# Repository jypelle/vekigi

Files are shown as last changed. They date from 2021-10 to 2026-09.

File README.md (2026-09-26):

# Vekigi

A 3D printable internet radio based on Golang and a Raspberry Pi Zero WH.

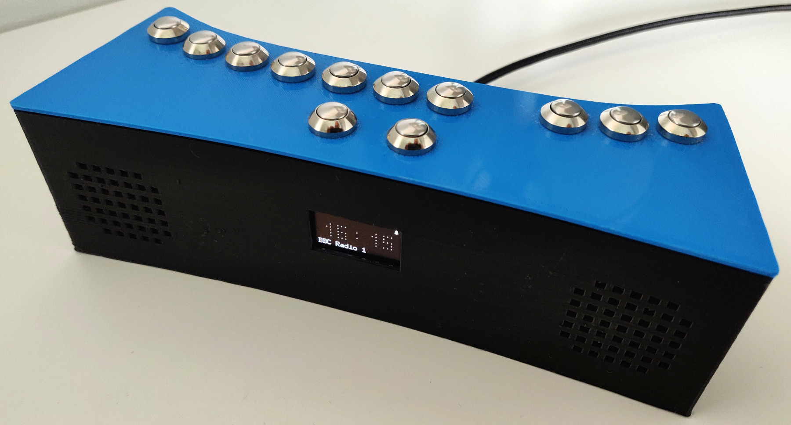
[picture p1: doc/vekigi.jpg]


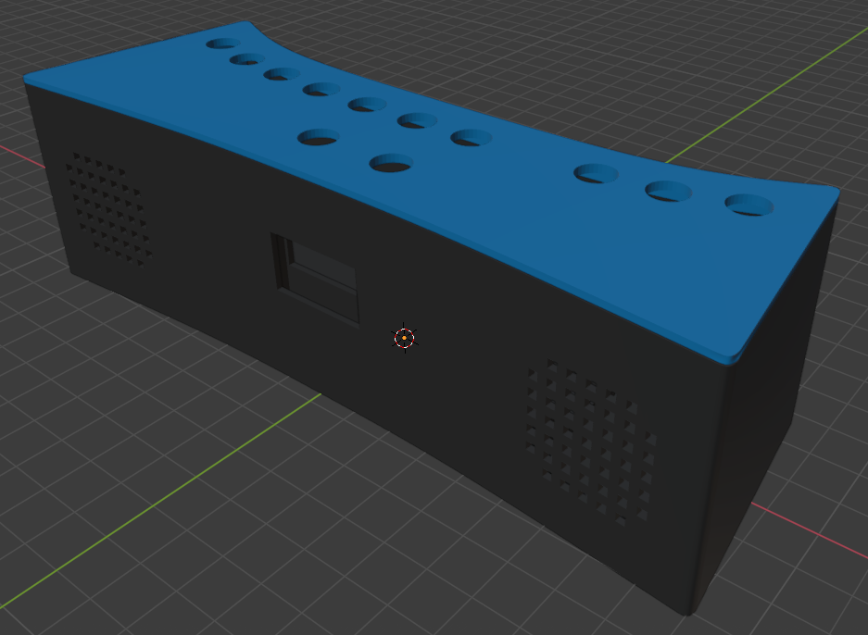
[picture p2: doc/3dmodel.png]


*NB: Vekiĝi means "to wake up" in esperanto.*

## Key features

- Alarm clock with adjustable snooze time (that's a killer feature 😜)
- REST API to easily interface with home automation
- Play
  - webradios (any audio stream playable by [VLC](https://www.videolan.org))
  - local playlists (folders with music files)
  - or remote playlists (through [Mifasol music server](https://github.com/jypelle/mifasol))

Read [the building instructions](doc/building.md) to build your own Vekigi and tune it with [the manual](doc/manual.md).

See [the changelog](CHANGELOG.md) for the release notes.

## Development

Requirements: [Go 1.27+](https://go.dev/dl/) and [Task](https://taskfile.dev).

| Command | Description |
|---|---|
| `task build` | Build the Raspberry Pi Zero binary (ARMv6) into `release/linux-arm/vekigisrv` |
| `task deploy` | Build, then deploy and restart the `vekigisrv` service on `pi@vekigi` through SSH |
| `task simulator` | Run Vekigi on your computer, the OLED display being simulated in a window (debug mode) |

### Simulator

The simulator is only included in binaries built with `-tags simulator`: it displays the OLED screen in a window and simulates the buttons with the keyboard.

| Key | Button |
|---|---|
| `1`-`6` (top row or numpad) | Digits |
| `P` | Playlist |
| `Enter` | Alarm setting |
| `Up` / `Down` (or numpad `+` / `-`) | More / Less |
| `Space` | Snooze |
| `Right` | Next / Power off |

Sound relies on `aplay` and `amixer` (from `alsa-utils`, `aplay` being required to start the server) and on `cvlc` (from [VLC](https://www.videolan.org)) to play webradios and playlists.

## License

Copyright 2021-2026 Jean-Yves Pellé <jy@pelle.link>

Vekigi is a free and open source project distributed under the permissive [Apache 2.0 License](LICENSE).

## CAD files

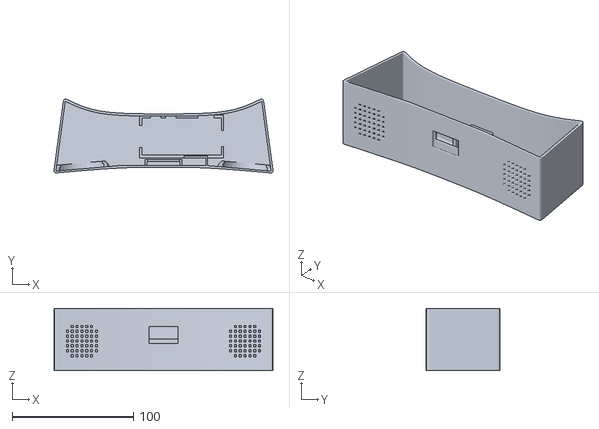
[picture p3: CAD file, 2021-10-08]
doc/case.stl
180.8 x 60.9 x 51.5

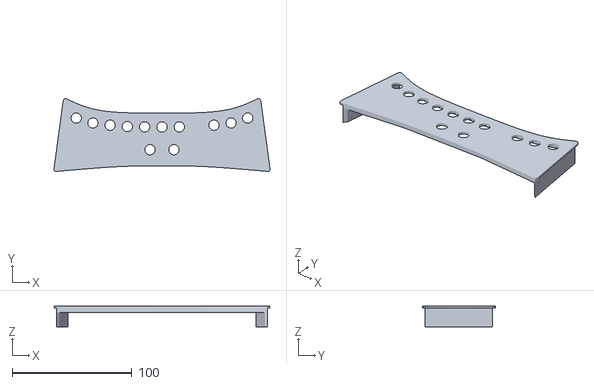
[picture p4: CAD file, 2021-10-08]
doc/cover.stl
180.8 x 60.9 x 17.2

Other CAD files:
doc/3dmodel.blend

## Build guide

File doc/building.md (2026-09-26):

# How to build your *Vekigi*

## Supplies

You will need:

- Raspberry pi zero wh
- [Adafruit I2S 3W stereo speaker bonnet](https://www.adafruit.com/product/3346)
- 5V 2.5A micro-USB power supply
- 32Gb class 10 micro SD card (or more if you want to store local playlists)
- SSD1306 0.96 Inch OLED Display 128x64 I2C   
- 2x Speakers (3W 4 ohms, 4cm diameter)
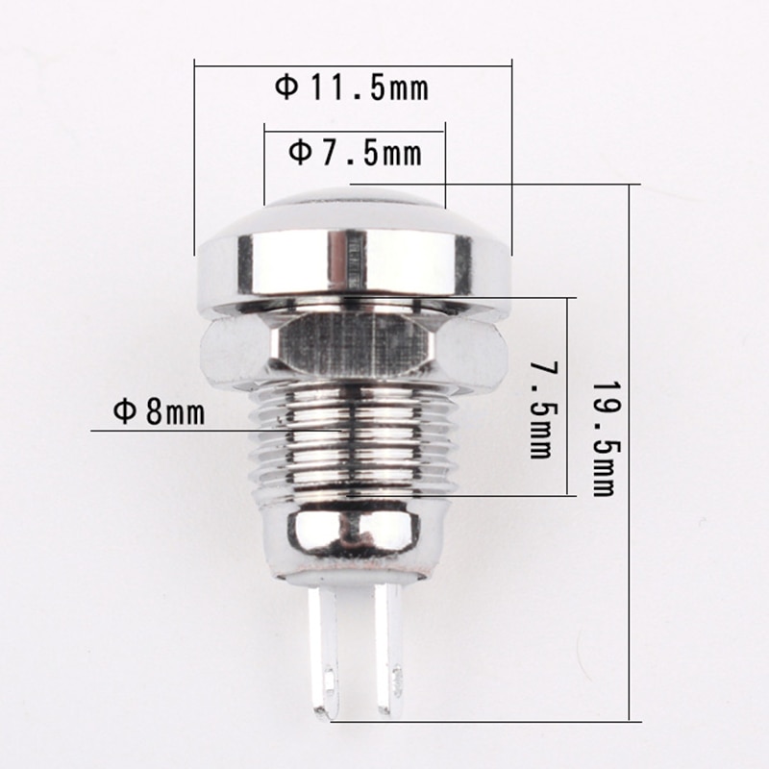
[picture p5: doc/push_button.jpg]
- 11x [8mm momentary push-button switches](https://fr.aliexpress.com/item/4000043687021.html?spm=a2g0s.9042311.0.0.55246c37O4olh8) 
- Single-sided prototype board (45 x 5 mm)
- [Tinned copper silicone wires 24AWG 0.2mm²](https://www.amazon.fr/gp/product/B07WLNR814)
- Solder wire (0.8mm)
- 3D printer with 1.75mm PLA filament

## Building 

### Printing the components

Print [case.stl](case.stl) and [cover.stl](cover.stl) with those parameters:

- Filament: PLA (one color for the case, another for the cover)
- Resolution: 0.2mm
- Infill: 40%
- Supports: Yes
  
NB: STL files comes from [3dmodel.blend](3dmodel.blend). You can customize them if you want.

### Switches

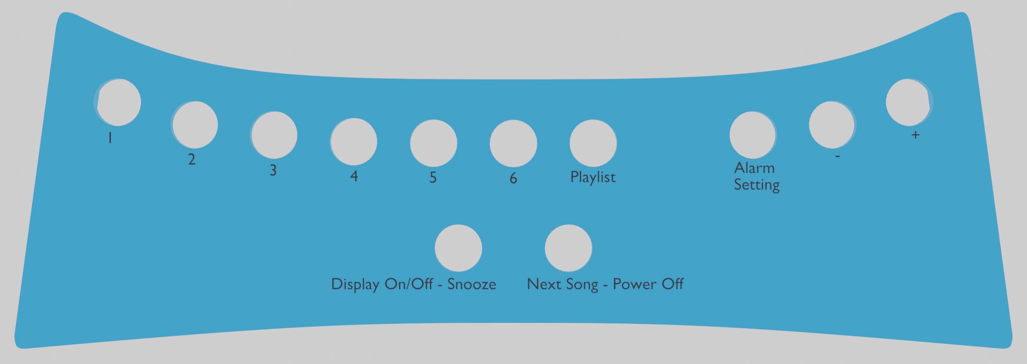
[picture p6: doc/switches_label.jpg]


Attach the 11 switches to the cover.
  
### Soldering

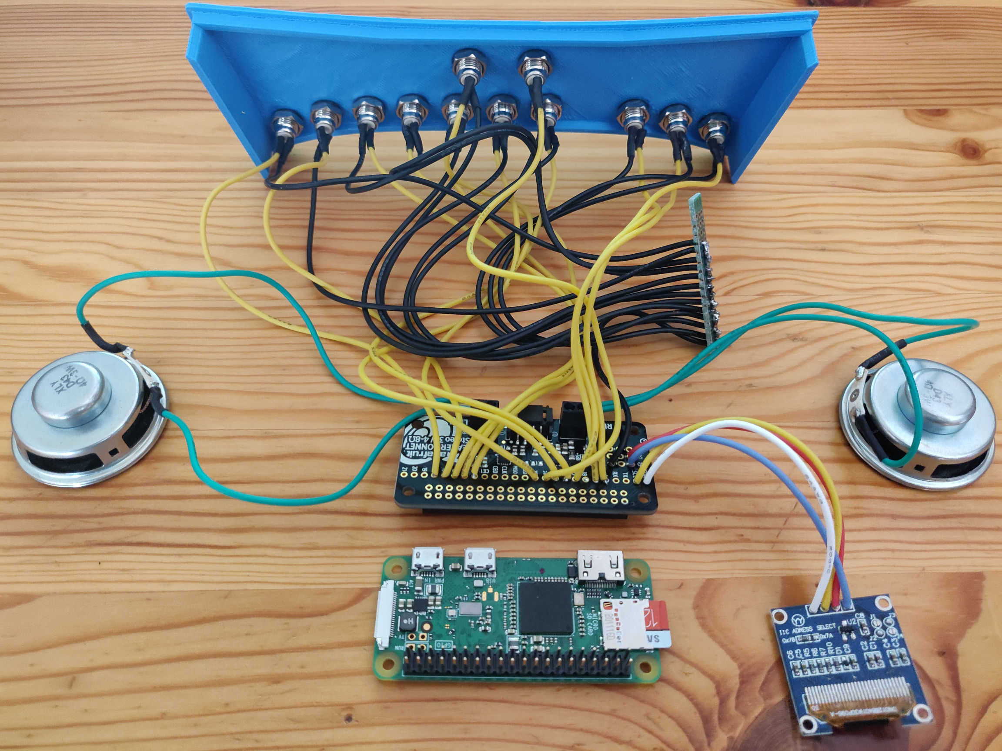
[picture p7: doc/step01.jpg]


First, there is no soldering to do on the raspberry pi.

All the soldering to be done will be deported to the Adafruit Bonnet:

- For the 11 switches and the Adafruit Bonnet, solder a black wire to connect its ground to the prototype board (which will be used to link them all).

- For each speaker, solder 2 green wires to connect to each bonnet's terminal block (left & right).

- For the OLED display, the link with the bonnet will be done through 4 wires to solder:

  - Ground <-> Ground 
  - 5V <-> 5V  
  - SCL <-> SCL
  - SDA <-> SDA

- For the 11 switches, solder a yellow wire on the remaining pin:

  - "1" switch <-> GPIO 16 pin's bonnet
  - "2" switch <-> GPIO 13
  - "3" switch <-> GPIO 12
  - "4" switch <-> GPIO 6
  - "5" switch <-> GPIO 5
  - "6" switch <-> GPIO 23
  - "PLAYLIST" switch <-> GPIO 22 
  - "ALARM SETTING" switch <-> GPIO 27
  - "-" switch <-> GPIO 17
  - "+" switch <-> GPIO 04
  - "Display On/Off - Snooze" switch <-> GPIO 25 
  - "Next song - Power off" switch <-> GPIO 24

### Assembling

Insert the 2 speakers in their respective slots.

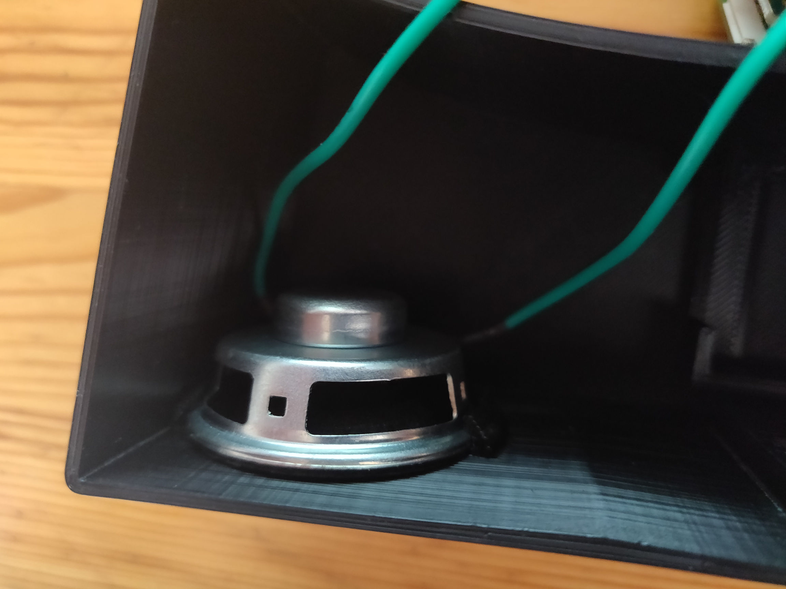
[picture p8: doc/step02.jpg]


Plug the Adafruit bonnet on the Raspberry Pi.

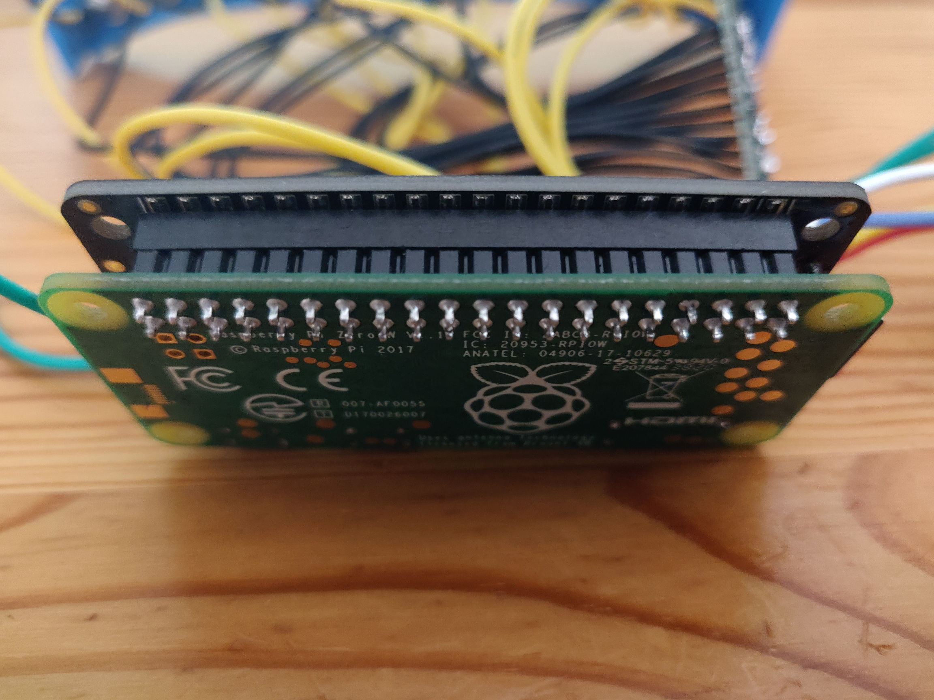
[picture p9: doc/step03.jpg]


Insert them at the center of the case.

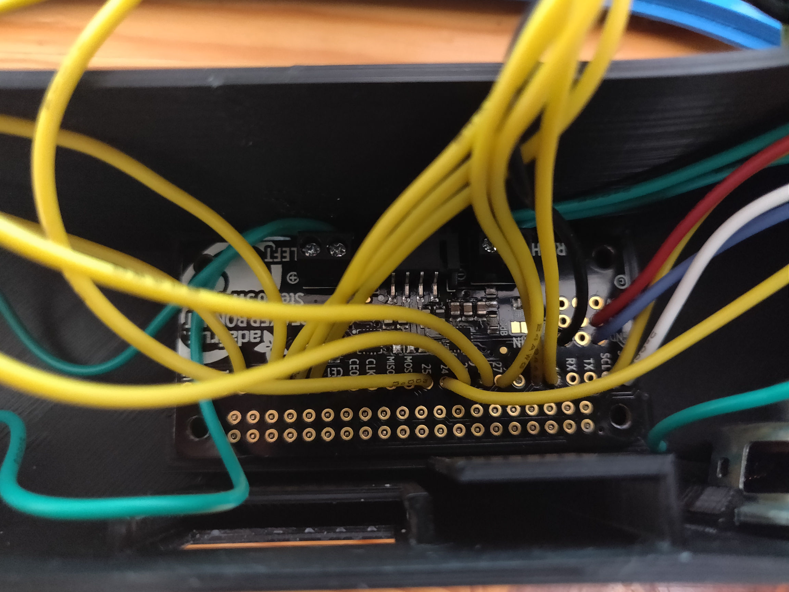
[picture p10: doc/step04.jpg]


Slide the prototype board into its dedicated slot.

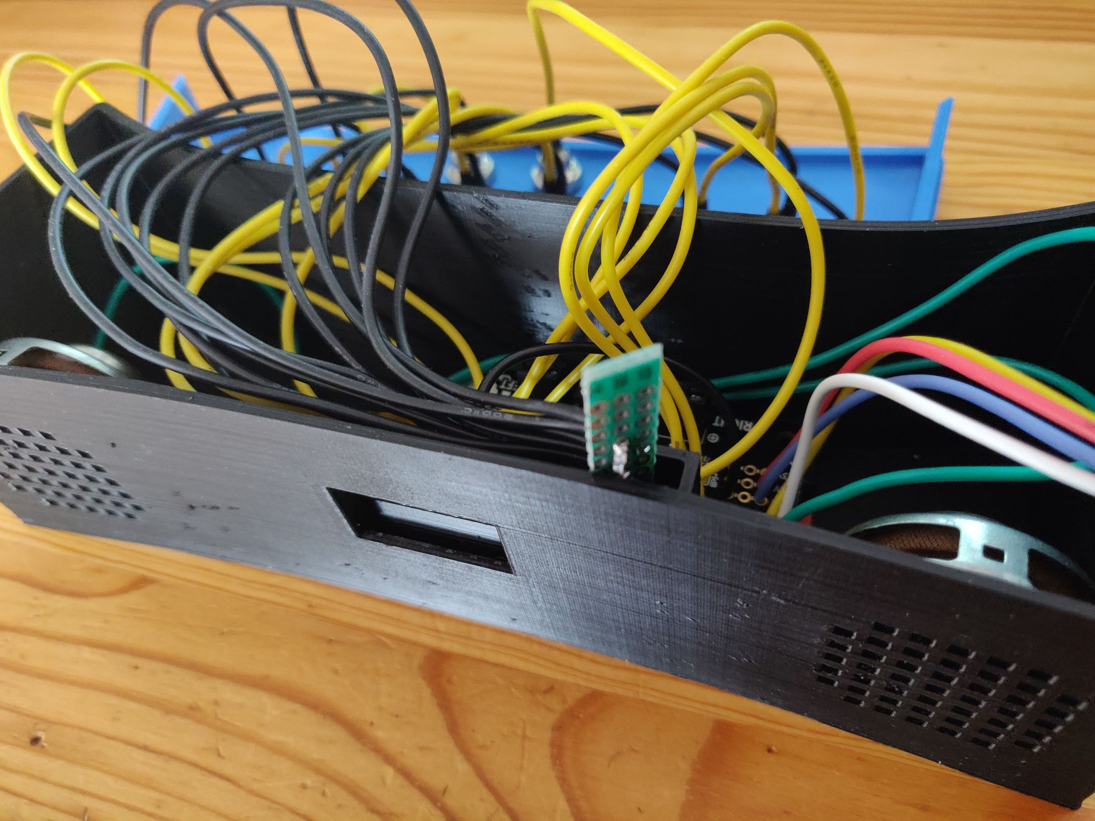
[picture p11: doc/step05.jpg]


Do the same with the OLED display.

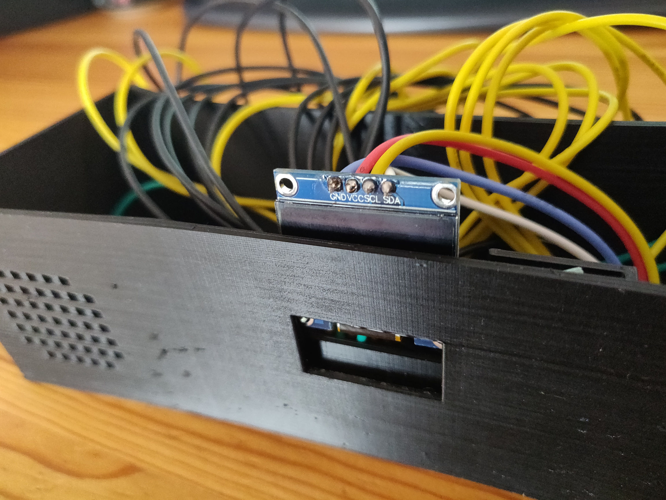
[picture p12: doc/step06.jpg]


And voilà !

### Installing

#### Pi zero W

- Download and launch [Raspberry Pi Imager](https://www.raspberrypi.com/software/)
- Select the *Raspberry Pi Zero* device and the *Raspberry Pi OS Lite (32-bit)* image
- Customise the OS settings when asked:
  - Hostname: `vekigi` (or `vekigi2` to avoid conflicts with another vekigi)
  - Username: `pi`, with the password of your choice
  - Your wifi credentials
  - Your time zone
  - Enable SSH
- Install image to the microSD Card
- Insert the sd card into the Pi, and start it
- Wait 5 minutes
- Use your router to find Pi's IP address.
- Execute `sudo nano /etc/hosts` from a computer connected to the same lan to add vekigi's IP :
  ```
  XX.XX.XX.XX vekigi
  ```
- Connect to the PI through SSH: `ssh pi@vekigi`
- Execute `sudo apt update` && `sudo apt upgrade`
- Execute `sudo raspi-config`
  - Enable I2C (in *Interface Options*)
- Execute `sudo nano /etc/asound.conf` to enable speakers:

```
pcm.speakerbonnet {
   type hw card 0
}

pcm.dmixer {
   type dmix
   ipc_key 1024
   ipc_perm 0666
   slave {
     pcm "speakerbonnet"
     period_time 0
     period_size 1024
     buffer_size 8192
     rate 44100
     channels 2
   }
}

ctl.dmixer {
    type hw card 0
}

pcm.softvol {
    type softvol
    slave.pcm "dmixer"
    control.name "PCM"
    control.card 0
}

ctl.softvol {
    type hw card 0
}

pcm.!default {
    type             plug
    slave.pcm       "softvol"
}
```

- Execute `sudo nano /boot/firmware/config.txt` (`/boot/config.txt` on releases older than Bookworm):

```
#dtparam=audio=on
dtoverlay=hifiberry-dac
dtoverlay=i2s-mmap
```

- Restart the Pi with `sudo reboot`

- Reconnect to the PI through SSH: `ssh pi@vekigi`

#### VLC and ALSA utils

```bash
sudo apt install vlc alsa-utils
```

#### Vekigi server

##### Add service to auto start and stop vekigi server

- Create systemd service file

    ```
    sudo touch /etc/systemd/system/vekigisrv.service
    sudo chmod 664 /etc/systemd/system/vekigisrv.service
    ```

- Edit /etc/systemd/system/vekigisrv.service

    ```
    [Unit]
    Description=Vekigi server
    
    [Service]
    Type=simple
    Restart=on-failure
    ExecStart=/home/pi/vekigisrv run
    User=pi
    Group=pi
    
    [Install]
    WantedBy=multi-user.target
    ```

- Enable vekigi server

    ```
    sudo systemctl daemon-reload
    sudo systemctl enable vekigisrv.service
    ```

##### Install

###### From source

- Install [Go 1.27+](https://go.dev/dl/) and [Task](https://taskfile.dev) on a computer connected to the same lan
- Execute `task deploy` from the Vekigi source folder: it builds the server binary, copies it to `pi@vekigi` and starts the service
- Wait a few minutes to see the time displayed on your *Vekigi*

###### From prebuilt binary

- Copy the `vekigisrv` binary built for Linux ARMv6 (`task build` puts it in `release/linux-arm/vekigisrv`) to `/home/pi/vekigisrv`
- Execute `chmod a+x /home/pi/vekigisrv`
- Start vekigi server with `sudo systemctl start vekigisrv.service`
- Wait a few minutes to see the time displayed on your *Vekigi*

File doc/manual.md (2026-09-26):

# User manual

Your Vekigi is built and operational? Great! Let's see how to use and tune it.

## Buttons

Most buttons react differently to a short press and to a long press (the button being held down).

| Button | Short press | Long press |
|---|---|---|
| `1` to `6` | Play the first webradio of the group, then the next ones | Cycle through the webradios of the group (about every half second) |
| `PLAYLIST` | Play the next playlist | Cycle through the playlists (about every half second) |
| `ALARM SETTING` | Enter / leave the alarm settings | ~1 s: enable / disable the alarm |
| `-` / `+` | Decrease / increase the volume | Keep changing the volume |
| `Display On/Off - Snooze` | Switch the display on / off | ~0.6 s: stop the sound (snooze if the alarm is ringing)<br>~2 s: stop the sound and cancel the snooze ("Snooze off") |
| `Next song - Power off` | Play the next song of the current playlist | ~3 s: power off the Vekigi ("See you!") |

In the alarm settings, the `1` to `6`, `PLAYLIST` and `-` / `+` buttons change the alarm instead (see below).

## Display

The display shows the current time and, at the bottom, the name of the webradio or of the playlist and song being played (scrolling when too long).

In the top right corner:

- the alarm icon means the alarm is enabled
- the snooze icon means the alarm has rung and will ring again after the snooze time

A volume gauge pops up when the volume changes.

## Alarm

### Set the alarm

- Press `ALARM SETTING`: the display shows *Alarm settings* with the alarm time and sound
- Use `-` / `+` to change the time: 1 minute at a time, then 5 minutes after holding the button ~3 s, then 30 minutes after ~5 s
- Choose the sound to wake up with:
  - `1` to `6`: a webradio of the group (press again to select the next webradio of the group)
  - `PLAYLIST`: a playlist (press again to select the next one)
- Press `ALARM SETTING` again to go back to the clock

The alarm is saved automatically.

### Enable or disable the alarm

From the clock, hold `ALARM SETTING` for about 1 second: the alarm icon appears or disappears.

### When the alarm rings

The selected webradio or playlist starts playing and the snooze icon appears.

- Hold `Display On/Off - Snooze` for ~0.6 s to stop the sound: the alarm will ring again after the snooze time (10 minutes by default)
- Keep holding it for ~2 s to also cancel the snooze: *Snooze off* is displayed and the alarm won't ring again before the next day

Playing a webradio or a playlist also cancels the snooze.

### Weekends

To skip the alarm on Saturdays and Sundays, set `no_alarm_on_weekends` to `true` in the `state.yaml` file (see [State file](#state-file)).

## Webradios

Webradios are organized in 6 groups, one for each `1` to `6` button. Pressing a digit button plays the first webradio of its group, pressing it again plays the next one, and so on.

The list of webradios is set in the config file (see [Config file](#config-file)).

## Playlists

The `PLAYLIST` button plays the playlists one after another. Songs of a playlist are played in random order, and the playback stops after the last song.

Playlists come from one of these sources:

- **Local playlists** (default): each subfolder of `~/.config/vekigi/playlist` is a playlist (sorted by name), containing music files playable by [VLC](https://www.videolan.org). For instance, to copy a folder from your computer:

  ```bash
  ssh pi@vekigi "mkdir -p .config/vekigi/playlist"
  scp -r "My playlist" pi@vekigi:.config/vekigi/playlist/
  ```

- **Remote playlists**: when the `mifasol` section is set in the config file, the playlists are the favorite playlists of the Mifasol user (sorted by name), played from your [Mifasol music server](https://github.com/jypelle/mifasol).

## Configuration

The Vekigi stores its configuration in `~/.config/vekigi` (another folder can be used with the `-c` option of `vekigisrv`). Both files are created with default values at the first start.

To edit them:

- Connect to your Vekigi through SSH: `ssh pi@vekigi`
- Stop the Vekigi server: `sudo systemctl stop vekigisrv.service`
- Edit the file, for instance: `nano .config/vekigi/param.yaml`
- Start the Vekigi server: `sudo systemctl start vekigisrv.service`

NB: the server must be stopped before editing `state.yaml`, otherwise your changes would be overwritten.

### Config file

`param.yaml`:

```yaml
# Snooze time, in seconds
snooze_duration: 600

# Webradios of each group (1 to 6 for the digit buttons), in order
webradio_groups:
  1:
    - name: France info
      url: http://direct.franceinfo.fr/live/franceinfo-hifi.aac
    - name: France bleu nord
      url: http://direct.francebleu.fr/live/fbnord-midfi.mp3
  2:
    - name: FIP Jazz
      url: http://icecast.radiofrance.fr/fipjazz-hifi.aac
  # ...

# Optional: use the favorite playlists of a Mifasol user instead of the local playlists
mifasol:
  hostname: localhost
  port: 6620
  ssl: true
  self_signed: true
  username: mifasol
  password: mifasol
  timeout: 600

# REST API
api:
  enabled: true # Set to false to disable the REST API
  ssl_port: 6650
  api_key: timesup
```

Any audio stream playable by [VLC](https://www.videolan.org) can be used as a webradio `url`.

Don't forget to change the default `api_key`.

### State file

`state.yaml` holds what the Vekigi remembers between restarts. It is saved automatically a few seconds after each change made with the buttons or the API.

```yaml
# Volume, from 0 to 100
volume: 40
alarm:
  hour: 8
  minute: 0
  # Alarm sound: either a webradio or a playlist (the other one being null)
  webradio_id:
    group_id: 1 # Group (digit button)
    index_id: 1 # Position of the webradio in the group, starting from 1
  playlist_id: null # Position of the playlist, starting from 1
  enabled: true
  # Set to true to skip the alarm on Saturdays and Sundays
  no_alarm_on_weekends: false
```

## REST API

The Vekigi can be controlled from your home automation system with a REST API, served over HTTPS on the `ssl_port` of the config file.

A self-signed certificate is generated at the first start (`cert.pem` and `key.pem` in the config folder): with curl, use `-k` to accept it.

Each request must send the `api_key` of the config file in the `x-api-key` header.

| Request | Description |
|---|---|
| `GET /api/is_alive` | Check that the Vekigi is up |
| `POST /api/webradio/play/{group_id}/{index_id}` | Play the webradio at position `index_id` (from 1) of the group  |
| `POST /api/playlist/play/{playlist_id}` | Play the playlist at position `playlist_id` (from 1) |
| `POST /api/audio/volume/{volume}` | Set the volume (0 to 100) |

For instance, to play the second webradio of the first group:

```bash
curl -k -X POST -H "x-api-key: timesup" https://vekigi:6650/api/webradio/play/1/2
```

The API answers with a `200` status on success, `403` for a wrong API key or an unknown webradio / playlist, and `400` for invalid parameters.

## Power off

Hold `Next song - Power off` for about 3 seconds: *See you!* is displayed and the Vekigi shuts down. Wait a few seconds before unplugging it.

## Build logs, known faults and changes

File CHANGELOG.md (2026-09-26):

## v1.1.0

*2026-09-26*

- New features:
  - **Simulator buttons**: the 12 buttons of the Vekigi can now be pressed from the keyboard in the simulator (same auto-repeat as the real buttons when held down)
    - `1`-`6` (top row or numpad): digit buttons
    - `P`: playlist
    - `Enter`: alarm setting
    - `Up` / `Down` (or numpad `+` / `-`): more / less
    - `Space`: snooze
    - `Right`: next / power off
- Enhancements:
  - **Simulator** rewritten with [Ebitengine](https://ebitengine.org) (replaces Gio):
    - Pixel-perfect rendering of the OLED display, which now also shows a black screen when the display is switched off
    - No longer requires cgo nor any system library to build
    - **Breaking change**: simulation mode is now enabled at build time with `-tags simulator` (the `-s` flag is removed), use `task simulator` to run it
  - Structured logs with `log/slog`
  - Build with Go 1.27 and [Task](https://taskfile.dev) (`task build`, `task deploy`, `task simulator`) instead of make
  - Update dependencies
- Bug fixes:
  - The `api.enabled` param is now taken into account: set it to `false` to disable the REST API
  - The ARM binary is now explicitly built for ARMv6, as required by the Raspberry Pi Zero (recent Go versions target ARMv7 by default)
  - A stop signal received while the server was busy could be missed
  - Some log messages were missing the error details (popping/clicking cleaner, volume, playlist songs)

## v1.0.0

*2021-10-08*

- Initial release:
  - Alarm clock with adjustable snooze time
  - REST API
  - Play webradios, local playlists or remote playlists (through [Mifasol music server](https://github.com/jypelle/mifasol))
  - `no_alarm_on_weekends` param to skip the alarm on saturdays and sundays (added on 2022-01-08)

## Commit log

2021-10-08 First big commit
    [3dmodel.blend, case.stl, cover.stl]
2026-09-26 Vekigi v1.1.0: Go 1.27, Ebitengine simulator with keyboard buttons, slog
    - Update to Go 1.27.1 and update all dependencies (Mifasol client v0.5.0, bitmapfont v3, periph.io, ...)
    - Replace the Makefile with a Taskfile (build, deploy, simulator)
    - Build the Raspberry Pi Zero binary for ARMv6 explicitly (Go now defaults to ARMv7 when cross-compiling)
    - Replace logrus with log/slog and tint
    - Rewrite the simulator with Ebitengine instead of Gio: no cgo needed,
    pixel-perfect rendering, and the 12 buttons simulated with the keyboard
    - Enable the simulator with the "simulator" build tag instead of the -s flag
    - Honor the api.enabled param
    - Fix missed stop signals (unbuffered signal channel) and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
2026-09-30 Move to the next webradio when the previous one ended by itself
    When vlc exits on its own (stream ended or failed), the player now remembers
    the ended radio so that pressing the group button again in clock mode plays
    the next radio of the group instead of restarting from the first one.
